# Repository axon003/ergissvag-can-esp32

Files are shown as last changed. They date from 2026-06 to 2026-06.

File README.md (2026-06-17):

# ErgissVAG CAN — ESP32 listen-only CAN tap for VW / Seat / Škoda / Audi

Open-source ESP32 firmware that taps the **CAN-Antrieb / CAN-Komfort** bus of VAG-group
cars (VW, Seat, Škoda, Audi — e.g. Touran, Seat Altea XL) in **listen-only** mode and
streams decoded vehicle data — wheel speeds, yaw rate, steering angle, brake, RPM — as
JSON over WiFi to a companion Android app.

> 📱 **Companion app: [ErgissVAG F16 on Google Play](https://play.google.com/store/apps/details?id=ro.ergiss.vag.f16)**
> — live VAG dashboard, gauges and trip telemetry. This firmware is the optional hardware
> module that feeds it the original CAN data the OBD port doesn't expose.

## Why
The OBD-II port on VAG cars exposes only a limited PID set through the J533 gateway.
Signals like individual **wheel speeds, yaw rate, lateral acceleration, steering angle and
original brake data** live on the internal CAN-Antrieb bus. This module is a **passive,
listen-only tap** — it never writes to the bus (safe, non-intrusive) — that decodes those
frames and serves them to the app over WiFi.

## Features
- ESP32 (native TWAI CAN driver) + SN65HVD230 transceiver — **listen-only, never transmits**
- Decodes CAN-Antrieb (500 kbit) / CAN-Komfort (100 kbit)
- WiFi AP + TCP JSON stream (or STA mode to join your own router)
- Optional GY-85 IMU (accel / gyro / magnetometer) + BMP280 barometer for motion & altitude
- Deep-sleep with wake-on-CAN — sleeps when the car is off
- 3D-printable enclosure (`case.scad` / `case.stl`)
- Two build layouts: Arduino IDE sketch (`ergissvag_can/`) and PlatformIO (`esp32/`)

## Hardware
- ESP32 DevKit v1 + SN65HVD230 CAN transceiver
- (optional) GY-85 IMU + BMP280

⚠️ **Safety:** listen-only tap, inline fuse, never connect TX. You are responsible for any
work on your vehicle's wiring.

## Quick start
1. Flash via PlatformIO (`pio run -t upload`) or Arduino IDE (open `ergissvag_can.ino`).
2. In `config.h` set your own `WIFI_AP_PASS` (STA fields are placeholders by default).
3. Power the module, connect the **ErgissVAG F16** app to the WiFi AP — data flows as JSON.

## License
**PolyForm Noncommercial License 1.0.0** — free for noncommercial use. See [`LICENSE.md`](LICENSE.md).
**Commercial use requires a separate license** — contact **office@ergiss.ro**.

Copyright © Gabriel Diaconu / ERGISS Media.

---
Built by **ERGISS Media** — [ergiss.ro](https://www.ergiss.ro) · [mensoft.ro](https://www.mensoft.ro)
Android: **[ErgissVAG F16 on Google Play](https://play.google.com/store/apps/details?id=ro.ergiss.vag.f16)**

## Support

If this helps you, you can buy me a coffee: **[paypal.me/axon003](https://paypal.me/axon003)**. Thank you!

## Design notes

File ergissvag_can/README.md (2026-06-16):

# ergissvag_can — Arduino IDE sketch

Arduino IDE build (folder name = sketch name). Functionally equivalent to `esp32/` (PlatformIO).

## Arduino IDE setup

### 1. ESP32 board

`File → Preferences → Additional Boards Manager URLs`:
```
https://raw.githubusercontent.com/espressif/arduino-esp32/gh-pages/package_esp32_index.json
```
Then `Tools → Board → Boards Manager` → search **"esp32"** by Espressif → install the latest (3.x+).

Select board: **Tools → Board → ESP32 Arduino → ESP32 Dev Module**
Upload speed: 921600
Flash size: 4MB
Partition scheme: Default 4MB with spiffs

### 2. Libraries (Sketch → Include Library → Manage Libraries)

| Library | Author | Note |
|---|---|---|
| **Adafruit BMP280 Library** | Adafruit | pressure/temperature sensor |
| **Adafruit ADXL345** | Adafruit | GY-85 accelerometer |
| **Adafruit HMC5883 Unified** | Adafruit | GY-85 magnetometer |
| **Adafruit Unified Sensor** | Adafruit | common dependency (BusIO + Sensor base) |

> ITG3200 (gyroscope) is read raw over I2C in `sensors.cpp` — no library needed.

> `ESPmDNS`, `WiFi`, `driver/twai.h` ship with the ESP32 core — no separate install.

### 3. Open + Upload

`File → Open` → select `ergissvag_can.ino`. The Arduino IDE automatically includes
`config.h`, `sensors.h`, `sensors.cpp` (same folder).

Upload (Ctrl+U) with the ESP32 on USB. On the DevKit V1 you don't need to hold anything —
auto-reset works through the USB-Serial chip.

## Hardware

| Connection | ESP32 pin |
|---|---|
| BMP280 + GY-85 (I2C SDA) | **GPIO 21** |
| BMP280 + GY-85 (I2C SCL) | **GPIO 22** |
| SN65HVD230 CTX (CAN TX) | **GPIO 17** (TX2) |
| SN65HVD230 CRX (CAN RX) | **GPIO 16** (RX2) |
| Module power | **3V3** + **GND** |

## Network access

- mDNS hostname: **`ergisscan.local`**
- TCP JSON server: port **31416**
- WiFi STA: `YOUR_WIFI_SSID` / `YOUR_WIFI_PASSWORD` (set in `config.h`)
- Fallback AP if STA fails: `ergCAN_ESP32` / `ergcan2026`

Test: `nc ergisscan.local 31416` (or `ncat`, `telnet`, `socat`)

## Quick config changes

Edit **`config.h`**:
- `CAN_BITRATE` — 500000 (Antrieb) / 100000 (Komfort)
- `WIFI_STA_SSID` / `WIFI_STA_PASS` — set to your own router
- `SENSOR_SAMPLE_MS` — 100 ms default (10 Hz); 50 ms = 20 Hz; 200 ms = 5 Hz
- `MDNS_HOSTNAME` — change the `.local` name

## See also

- `esp32/` — PlatformIO version (CLI build)
- [ErgissVAG F16 on Google Play](https://play.google.com/store/apps/details?id=ro.ergiss.vag.f16) — companion app

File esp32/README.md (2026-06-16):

# ergissvag_can — ESP32 J533 CAN tap (listen-only)

ESP32 DevKit v1 + SN65HVD230 firmware that sniffs the **CAN-Antrieb** or **CAN-Komfort**
bus (VW PQ35 — Seat Altea XL 2011 / Touran CBZB, J533 gateway) and streams decoded frames
as JSON over TCP to a companion Android app
([**ErgissVAG F16**](https://play.google.com/store/apps/details?id=ro.ergiss.vag.f16)).

- Author: Gabriel Diaconu (ERGISS Media)
- Version: 1.0 (2026-04-22)
- Framework: PlatformIO + Arduino-ESP32
- CAN driver: native ESP32 TWAI (`driver/twai.h`)

## Layout

```
esp32/
  platformio.ini      # board esp32dev + arduino framework
  src/
    main.cpp          # firmware (TWAI + WiFi AP + TCP server + deep sleep)
    config.h          # constants (bitrate, SSID, TCP port, pins, timing)
  README.md
```

## Flash

### PlatformIO (recommended)

```bash
cd esp32
pio run                              # compile
pio run -t upload                    # flash via USB (auto-detect port)
pio device monitor -b 115200         # serial log
```

### Arduino IDE

1. Board Manager -> install `esp32` by Espressif Systems
2. Board: `ESP32 Dev Module`, Upload speed 921600, Flash 4MB, Partition `Default`
3. Copy `src/main.cpp` as `main.ino` into a `main/` folder, put `config.h` next to it
4. Tools -> Port, Upload, then Serial Monitor 115200

## Config

Edit `src/config.h`:

| Define | Default | Note |
|---|---|---|
| `CAN_BITRATE` | 500000 | 500k = Antrieb, 100k = Komfort |
| `WIFI_AP_SSID` | `ergCAN_ESP32` | |
| `WIFI_AP_PASS` | `ergcan2026` | WPA2, min 8 chars — **change this** |
| `TCP_PORT` | 31416 | |
| `DEEP_SLEEP_IDLE_S`  | 30 | seconds with no client -> sleep |
| `HB_INTERVAL_MS` | 5000 | heartbeat JSON when no frames |

After editing: `pio run -t upload`.

## Wiring

### ESP32 DevKit v1 <-> SN65HVD230

```
   ESP32 DevKit v1                 SN65HVD230 (listen-only)
   +---------------+                +------------------+
   | GPIO21 (CTX)  |--------------->| D  (TXD)         |   not electrically driving the bus
   |               |                |                  |   (listen-only), but required to init TWAI
   | GPIO22 (CRX)  |<---------------| R  (RXD)         |
   | 3V3           |--------------->| VCC (3V3)        |
   | GND           |--------------->| GND              |
   |               |                | RS   ----- GND   |   <-- REQUIRED: high-speed mode
   |               |                | CANH ----------- | ---> J533 pin 6 (CAN-Antrieb HIGH)
   |               |                | CANL ----------- | ---> J533 pin 16 (CAN-Antrieb LOW)
   +---------------+                +------------------+
```

Notes:
- **RS to GND**: forces the SN65HVD230 into high-speed mode. For passive listen-only the
  driver simply never transmits (`TWAI_MODE_LISTEN_ONLY`). RS to 3V3 would enable
  slope-control (not wanted here).
- **Do NOT** add a 120R termination resistor — the bus is already terminated in the car.
- Keep CAN-H/L a **twisted pair**, 10-30 cm, not run parallel to the 12V supply.
- Power: the ESP32 on-board 3V3 regulator from 5V USB, or a 5V buck from OBD. For a
  permanent install use a 12V->5V step-down with quiescent current <1 mA.

### J533 gateway pinout — PQ35 (Altea XL / Touran / Leon 1P)

Connector T20a (green, 20-pin):

| Pin | Signal | Rate |
|-----|---|---|
| 6 | CAN-Antrieb HIGH | 500 kbps |
| 16  | CAN-Antrieb LOW | 500 kbps |

Connector T20b carries CAN-Komfort HIGH/LOW (100 kbps) and CAN-Infotainment (100 kbps).
J533 pinouts for the PQ35 platform are widely documented (see VW SSP 269).

## TCP protocol

- Port **31416**, WPA2 SSID **ergCAN_ESP32**, ESP32 IP = **192.168.4.1**
- One client at a time (a second connection is rejected)
- Banner on connect:
  ```json
  {"hello":"ergCAN","bitrate":500000,"port":31416}
  ```
- CAN frame (one line, `\n`-delimited):
  ```json
  {"ts":1234,"id":"0x470","ext":0,"rtr":0,"len":8,"data":"01 00 00 00 00 00 00 00"}
  ```
  - `ts`   = millis() since ESP32 boot
  - `id`   = hex CAN ID (11-bit or 29-bit depending on `ext`)
  - `ext`  = 0 standard, 1 extended
  - `rtr`  = 0 data, 1 remote transmission request
  - `len`  = DLC (0..8)
  - `data` = hex bytes, space-separated
- Heartbeat every 5 s when no frames arrive:
  ```json
  {"hb":1,"uptime":42,"rx_total":0,"rx_err":0}
  ```

## Android client pattern

```kotlin
// 1. Phone joins SSID "ergCAN_ESP32" (WPA2 "ergcan2026")
// 2. Socket to 192.168.4.1:31416
val sock = Socket()
sock.connect(InetSocketAddress("192.168.4.1", 31416), 3000)
val br = BufferedReader(InputStreamReader(sock.getInputStream()))
while (isActive) {
    val line = br.readLine() ?: break
    val obj = JSONObject(line)
    if (obj.optInt("hb") == 1) continue          // heartbeat
    val id   = obj.getString("id")               // "0x470"
    val len  = obj.getInt("len")
    val data = obj.getString("data")             // "01 00 ..."
    // decode...
}
```

The [ErgissVAG F16](https://play.google.com/store/apps/details?id=ro.ergiss.vag.f16) app
consumes this stream as one of its vehicle-data sources.

## Troubleshooting

| Symptom | Likely cause / fix |
|---|---|
| `rx=0` on Serial, no frames | Check RS=GND (not VCC!), check bitrate (500k/100k) |
| `state=BUS_OFF` in log | Wrong bitrate or CAN_H/L swapped |
| Continuous reboot | TWAI driver crash — check GPIO21/22 are connected |
| Android can't see the SSID | ESP32 in deep sleep — turn ignition on for wake-on-CAN |
| Connect accepted then dropped | Another client already connected (1-client limit) |
| `rx_err` rising fast | Bad termination — do **NOT** add 120R, the car has it |
| AP shows but won't connect | Password min 8 chars; reset ESP32 after changing config |

## Deep sleep & wake-on-CAN

After 30 s with no TCP client, the ESP32 enters deep sleep (~10 uA).
Wake source: GPIO22 (CAN RX) going HIGH — i.e. any bus activity after idle.

On PQ35:
- Ignition OFF, all buses asleep -> ESP32 sleeps
- Ignition ON or remote unlock -> CAN-Komfort/Antrieb wakes -> ESP32 wakes (a few ms)
- After wake the ESP32 restarts the AP + TCP server + TWAI

Average draw: ~80 mA @ 3V3 when active (WiFi AP), ~10 uA in deep sleep.

## References

- VW Self-Study Programme SSP 269 — CAN Data Bus (Antrieb + Komfort, PQ35)
- [ErgissVAG F16 on Google Play](https://play.google.com/store/apps/details?id=ro.ergiss.vag.f16)

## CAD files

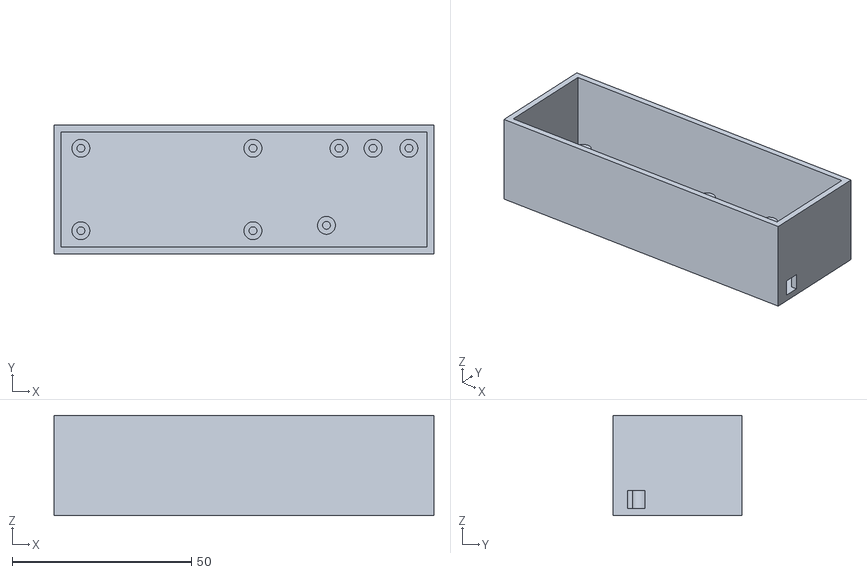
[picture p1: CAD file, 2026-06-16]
case.stl
106.0 x 36.0 x 28.0

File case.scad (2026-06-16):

// case.scad - cutie ESP32 DevKit V1 + 2 module aux (fara capac)
// @author Gabriel Diaconu (ERGISS Media)
// @version 1.2
// @changes
//   v1.0 2026-05-23 - creat initial
//   v1.1 2026-05-23 - adaugat modul 2 (16mm) cu 2 standoff
//   v1.2 2026-05-23 - module dispuse pe lungime (X), nu stivuite pe Y; standoff pe Y ambele

// --- parametri ESP32 DevKit V1 (DOIT 38-pin) ---
esp_pcb_l   = 55;     // lungime PCB (axa X)
esp_pcb_w   = 28;     // latime PCB (axa Y)
esp_hole_dx = 48;     // distanta intre gauri pe X
esp_hole_dy = 23;     // distanta intre gauri pe Y
esp_usb_w   = 10;     // latime cutout microUSB
esp_usb_h   = 6;      // inaltime cutout microUSB

// --- modul 1 (27 x 21.5 mm) ---
mod_l       = 27;     // lungime modul 1 (axa X)
mod_w       = 21.5;   // latime modul 1 (axa Y)
mod_gap     = 10;     // distanta intre ESP si modul 1 (axa X)

// --- modul 2 (16 x 16 mm) ---
mod2_l      = 16;     // lungime modul 2 (axa X)
mod2_w      = 16;     // latime modul 2 (axa Y)
mod2_gap    = 10;     // distanta intre modul 1 si modul 2 (axa X)
mod2_standoff_dx = 10; // separare intre cele 2 standoff modul 2 (axa X)

// --- standoffs ---
standoff_h  = 5;      // inaltime PCB peste podea
standoff_od = 5;      // diametru exterior
standoff_id = 2.2;    // diametru interior (M2.5 self-tap)

// --- cutie ---
wall        = 2;      // grosime perete
floor_h     = 2;      // grosime podea
margin      = 2;      // spatiu liber intre PCB si perete
box_h       = 28;     // inaltime totala perete

// --- derivate ---
inner_l = esp_pcb_l + mod_gap + mod_l + mod2_gap + mod2_l + 2*margin - 20;  // -20: standoff modul 2 mutate la stanga
inner_w = max(esp_pcb_w, mod_w, mod2_w) + 2*margin;
outer_l = inner_l + 2*wall;
outer_w = inner_w + 2*wall;

// pozitii (origine = coltul interior stanga-jos, peste podea)
esp_x0   = margin;
esp_y0   = (inner_w - esp_pcb_w) / 2;
mod_x0   = esp_x0 + esp_pcb_l + mod_gap;
mod_y0   = (inner_w - mod_w) / 2;
mod2_x0  = mod_x0 + mod_l + mod2_gap;
mod2_y0  = (inner_w - mod2_w) / 2;

$fn = 48;

// ===== CUTIE =====
difference() {
    translate([-wall, -wall, 0])
        cube([outer_l, outer_w, box_h]);

    translate([0, 0, floor_h])
        cube([inner_l, inner_w, box_h]);

    // cutout microUSB pe peretele stang
    usb_z_center = floor_h + standoff_h + 1.5;
    translate([-wall - 1, esp_y0 + esp_pcb_w/2 - esp_usb_w/2, usb_z_center - esp_usb_h/2])
        cube([wall + 2, esp_usb_w, esp_usb_h]);

    // cutout 5x5mm pentru fire pe peretele drept (latura scurta), in dreapta jos
    translate([inner_l - 1, margin, floor_h])
        cube([wall + 2, 5, 5]);
}

// ===== STANDOFFS ESP32 (4 colturi) =====
esp_cx = esp_x0 + esp_pcb_l/2;
esp_cy = esp_y0 + esp_pcb_w/2;
for (sx = [-1, 1], sy = [-1, 1])
    translate([esp_cx + sx*esp_hole_dx/2, esp_cy + sy*esp_hole_dy/2, floor_h])
        standoff();

// ===== STANDOFFS MODUL 1 (2 buc: sus la Y-ul ESP, jos cu dify=21.5 difx=-3.5) =====
mod_cx = mod_x0 + mod_l/2;
mod_cy = mod_y0 + mod_w/2;
mod1_top_x = mod_cx - 3;
mod1_top_y = esp_cy + esp_hole_dy/2;     // acelasi Y cu standoff-urile sus ale ESP
mod1_bot_x = mod1_top_x - 3.5;
mod1_bot_y = mod1_top_y - 21.5;
translate([mod1_top_x, mod1_top_y, floor_h]) standoff();
translate([mod1_bot_x, mod1_bot_y, floor_h]) standoff();

// ===== STANDOFFS MODUL 2 (2 buc, ambele sus aliniate la Y-ul ESP, separare pe X) =====
mod2_cx = mod2_x0 + mod2_l/2;
mod2_cy = mod2_y0 + mod2_w/2;
mod2_top_y = esp_cy + esp_hole_dy/2;
for (sx = [-1, 1])
    translate([mod2_cx + sx*mod2_standoff_dx/2 - 20, mod2_top_y, floor_h])
        standoff();

module standoff() {
    difference() {
        cylinder(h = standoff_h, d = standoff_od);
        translate([0, 0, 1])
            cylinder(h = standoff_h, d = standoff_id);
    }
}

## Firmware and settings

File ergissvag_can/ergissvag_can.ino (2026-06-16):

/**
 * main.cpp — ergissvag_can ESP32 J533 CAN tap + sensors + OBD master firmware
 * @author Gabriel Diaconu (ERGISS Media)
 * @version 1.24
 * @changes
 *   v1.24 2026-05-24
 *     - Fix `can` flag fals positive in discovery JSON: era doar `g_can_ok && g_can_bus_ok`,
 *       dar in listen-only fara TX, BUS_OFF nu se declanseaza chiar fara bus efectiv →
 *       flag ramanea true ne-corect. Adaugat verificare `lastFrameMs` (frame primit in <10s).
 *       APK corect trece pe ELM ca sursa OBD cand ergCAN nu primeste frame-uri.
 *   v1.23 2026-05-23
 *     - print_sensor_status() — sumar BMP/ADXL/ITG/MAG, apelat in init si la fiecare STAT (10s).
 *       Asa user vede status init si daca Serial Monitor s-a deschis dupa boot.
 *   v1.22 2026-05-23
 *     - Flag nou DEBUG_SERIAL_QUIET in config.h: cand 1 → emitJson() omitem Serial
 *       (Serial Monitor curat pt diagnoza init/scan/STAT). TCP continua sa trimita
 *       JSON normal pt APK. Default 0 = JSON pe ambele (Serial + TCP).
 *     - I2C revert 50kHz → 400kHz (cleanup test). Tot magnetometru absent — confirmat
 *       chip lipsa fizica; alimentare 5V pe pinul "3.3V" GY-85 (LDO intern) e singurul
 *       test ramas conform tutorial Instructables.
 *   v1.21 2026-05-23
 *     - I2C frecventa 400kHz → 50kHz (test detectie magnetometru cu timing extra tolerant).
 *   v1.20 2026-05-23
 *     - emitJson() reactivat pe Serial — JSON sensors stream apare din nou pe USB-Serial,
 *       pt conectare APK via USB CDC ACM ca alternativa la TCP/WiFi (port 31416).
 *       Serial Monitor in Arduino IDE va arata spam JSON la 10Hz — pt diagnoza pura,
 *       comentat Serial.write linia 230.
 *   v1.19 2026-05-23
 *     - Cleanup debug: I2C 100k → 400k, DISABLE_BMP280 → 0, dump 0x2C scos din STAT
 *       (chip identificat ca EEPROM pasiv board, ignorat). Scan I2C ramane in STAT 10s
 *       pt monitoring. Concluzie: HMC5883L lipseste fizic — cumpara GY-271 pt compass.
 *   v1.18 2026-05-23
 *     - DISABLE_BMP280=1 in config.h → test daca BMP280 init blocheaza HMC5883L pe bus.
 *       Daca dupa flash scan-ul arata 0x1E sau 0x0D → BMP cauzeaza conflict.
 *   v1.17 2026-05-23
 *     - sensors_debug_print() dump extins 0x2C reg 0x00..0x3F + activity test (2 citiri
 *       la 500ms distanta) — vad daca chip pasiv (EEPROM/OTP/ID) sau activ (sensor).
 *   v1.16 2026-05-23
 *     - sensors_debug_print() extins: forced-read probe pe 0x0C/0x0D/0x0E/0x1C/0x1D/0x1E/0x1F
 *       (toate adresele magnetometre cunoscute — pt cazul cand chip-ul prezent dar bug-uit
 *       nu raspunde la write-probe scan dar raspunde la read direct). HMC5883L ID check
 *       la 0x1E ('H','4','3' confirm).
 *   v1.15 2026-05-23
 *     - I2C frecventa scazuta 400kHz → 100kHz (standard mode) — tolerant la pull-up
 *       dublu (GY-85 + BMP280 ambele cu onboard pull-up) si cabluri zgomotoase.
 *   v1.14 2026-05-23
 *     - sensors_debug_print() apelat la fiecare ciclu STAT (10s) → scan I2C + dump 0x2C +
 *       write-read test vizibile si daca Serial Monitor a fost deschis dupa boot ESP32.
 *   v1.13 2026-05-23
 *     - Diagnoza adresa I2C 0x2C neasteptata: dump primii 16 regs + write-read test.
 *       Pattern-ul output identifica chip-ul (sau confirma ghost ACK).
 *   v1.12 2026-05-23
 *     - emitJson() NU mai trimite pe Serial (doar TCP). Serial Monitor ramane curat —
 *       vezi clar init logs ([I2C] scan + sensor detect + [WiFi] + [TCP] + [STAT] 10s).
 *       Pt re-activare debug Serial: decomenteaza Serial.write linia in emitJson().
 *   v1.11 2026-05-23
 *     - i2c_scan_print() la boot — printeaza toate adresele I2C detectate (diagnoza
 *       magnetometru). Vezi Serial Monitor: "[I2C] scan: 0x1E 0x53 0x68 0x76 (4 devices)"
 *       sau similar. Daca apare adresa neasteptata pt magnetometru → identificam clona.
 *   v1.10 2026-05-23
 *     - Magnetometru detect auto HMC5883L (Honeywell @0x1E) sau QMC5883L (QST clone @0x0D).
 *       Init manual via I2C (NU Adafruit_HMC5883_U care esueaza tacit pe clone) → date reale.
 *     - JSON "mag":{"chip":"HMC|QMC|none",...} pt diagnoza. APK ignora field-ul (parser flat).
 *     - Verificare ID HMC (regs 0x0A-C='H43') inainte init; QMC SET/RESET 0x01 + control 0x09.
 *     - Conversie LSB→µT corecta per chip (HMC 1.3G=10.9 LSB/µT, QMC 2G=12 LSB/µT).
 *   v1.9 2026-05-23
 *     - Fix bug "STA pierdut definitiv": dupa AP fallback, ESP32 retry STA la fiecare
 *       WIFI_STA_RETRY_S (60s). Cand HU hotspot/router revine dupa cadere, ESP32 se
 *       reconecteaza automat fara reboot. Inainte ramanea in AP `ergCAN_ESP32` la infinit.
 *   v1.8 2026-05-23
 *     - Discovery JSON include "can":<0|1> = stare CAN (g_can_ok && g_can_bus_ok).
 *     - APK F16 decide sursa OBD: can=1 → ergCAN inlocuieste BT ELM; can=0 → ELM ramane
 *       activ pt OBD, dar ergCAN ramane sursa pentru BMP280 + GY-85 (atitudine/BARO/IMU).
 *   v1.7 2026-05-23
 *     - UDP discovery trimite pe TREI destinatii: (1) UNICAST la gateway (WiFi.gatewayIP())
 *       — esential cand HU ruleaza hotspot; Android hotspot izoleaza broadcast intre clienti AP,
 *       dar nu filtreaza unicast catre gateway-ul AP-ului (HU);
 *       (2) Subnet broadcast (WiFi.broadcastIP() = ex 192.168.43.255) — pt alte device-uri din retea;
 *       (3) Limited 255.255.255.255 — fallback (mai mult Android-uri blocheaza, dar nu strica).
 *     - Confirmat functional cu HU + ESP32 client pe hotspot HU (varianta 1 = unicast).
 *   v1.6 2026-05-23
 *     - UDP broadcast discovery la fiecare UDP_BC_INTERVAL_MS (3s) pe 255.255.255.255:31417
 *     - Mesaj JSON {"app":"ergCAN","ip":"<IP>","tcp_port":31416,"ts":..,"fw":"1.7"}
 *     - APK F16 asculta UDP si auto-pornit TCP catre IP-ul descoperit. La 3 lipsuri (9s)
 *       APK marcheaza ergCAN offline si revine la fallback (BT ELM / device sensors).
 *     - Activ dupa WiFi STA up (sau AP fallback) — pornit din netServicesUp(); merge si in AP mode.
 *   v1.0 2026-04-22 — creat initial
 *     - TWAI listen-only (500k Antrieb / 100k Komfort config-selectabil)
 *     - WiFi AP "ergCAN_ESP32" (1 client)
 *     - TCP server port 31416, 1 frame = 1 linie JSON
 *     - Heartbeat 5s cand fara frames
 *     - Deep sleep 30s fara client + wake-on-CAN
 *     - Reboot auto la TWAI bus-off / hw error
 *   v1.1 2026-05-23
 *     - CAN mutat pe RX2/TX2 (GPIO 16/17) — 21/22 ocupati de I2C BMP280+GY-85
 *     - WiFi STA mode catre router "YOUR_WIFI_SSID" (cu fallback AP daca esueaza)
 *     - Senzori BMP280 + GY-85 (ADXL345 + ITG3200 + HMC5883L) pe I2C 21/22 @ 400kHz
 *     - JSON sensors emis pe Serial si TCP la fiecare 100ms (10Hz)
 *     - Scos deep sleep (alimentare din USB HU se taie cu contactul)
 *   v1.2 2026-05-23
 *     - mDNS hostname "ergisscan.local" — accesibil din LAN fara IP (nu are afisaj)
 *     - DHCP hostname set in STA mode (apare in lista router ca "ergisscan")
 *     - Anunt serviciu _ergcan._tcp.31416 pentru auto-discovery
 *   v1.3 2026-05-23
 *     - WiFi connect NON-BLOCKING — sensors+CAN+Serial emit imediat la boot
 *     - State machine in loop: WIFI_STA_TRYING -> WIFI_STA_OK | WIFI_AP_OK
 *     - mDNS + TCP server pornesc DUPA ce WiFi e up (la transition)
 *     - HU boot poate dura zeci de sec, dar Serial USB merge instant
 *   v1.4 2026-05-23
 *     - TWAI mode NORMAL (era LISTEN_ONLY) — pot transmite query OBD2/UDS pe bus
 *     - ISO-TP layer (iso_tp.cpp) — SF + FF/CF/FC, multi-ECU broadcast collection
 *     - OBD/UDS commands (obd_cmd.cpp) — mode 01/03/04/07/09 + UDS 10/19/22
 *     - USB JSON command parser (usb_proto.cpp) — F16 trimite query, ESP32 dispatches
 *     - DTC se citeste in broadcast 0x7DF → toate ECU-urile raspund pe 7E8-7EF
 *   v1.5 2026-05-23
 *     - Auto-recovery la BUS_OFF (fara reboot) — sensors+WiFi continua functional
 *     - Flag global g_can_bus_ok — iso_tp blocheaza TX cand bus absent
 *     - Eveniment JSON "buststate" emit la trans tranzitiile ok/bus_off
 *     - Alerts ALERT_BUS_RECOVERY_IN_PROGRESS / ALERT_BUS_RECOVERY_COMPLETE wired
 *
 * Hardware:
 *   ESP32 DevKit v1
 *     + SN65HVD230 (RS=GND silent listen-only)
 *       GPIO17 (TX2) -> CTX  (neconectat electric la CAN, doar init driver)
 *       GPIO16 (RX2) <- CRX
 *       3V3 + GND
 *       CAN_H/CAN_L la J533 pin 6/16 (CAN-Antrieb PQ35)
 *     + BMP280 (3.3V version) — adresa 0x76
 *     + GY-85 9DOF (ADXL345 0x53 + ITG3200 0x68 + HMC5883L 0x1E)
 *       3V3 + GND + GPIO21 (SDA) + GPIO22 (SCL)
 */

#include <Arduino.h>
#include <WiFi.h>
#include <WiFiServer.h>
#include <WiFiClient.h>
#include <WiFiUdp.h>
#include <ESPmDNS.h>
#include "driver/twai.h"
#include "esp_system.h"
#include "config.h"
#include "sensors.h"
#include "iso_tp.h"
#include "obd_cmd.h"
#include "usb_proto.h"

// ===== State =====
static WiFiServer tcpServer(TCP_PORT);
static WiFiClient tcpClient;
static WiFiUDP    udpDisc;             // UDP broadcast discovery 255.255.255.255:31417
static uint32_t   lastUdpBcMs = 0;

static uint32_t rxTotal      = 0;
static uint32_t rxErr        = 0;
static uint32_t lastFrameMs  = 0;
static uint32_t lastHbMs     = 0;
static uint32_t lastStatsMs  = 0;
static uint32_t lastSensorMs = 0;
static uint32_t ledOffAt     = 0;
static uint32_t bootMs       = 0;
static bool     g_can_ok     = false;

// WiFi state machine (non-blocking connect)
enum WifiState : uint8_t {
    WIFI_STA_TRYING,    // STA.begin() lansat, asteptam status WL_CONNECTED
    WIFI_STA_OK,        // STA conectat, mDNS+TCP up
    WIFI_AP_OK          // fallback AP activ dupa timeout STA
};
static WifiState g_wifi_state    = WIFI_STA_TRYING;
static uint32_t  g_wifi_start_ms = 0;
static bool      g_net_services_up = false;   // mDNS + TCP server pornite

// CAN bus state — blocheaza TX iso_tp cand bus absent (evita BUS_OFF loop)
volatile bool g_can_bus_ok = true;             // extern in iso_tp.cpp

// ===== Helpers =====

static void ledPulse() {
    digitalWrite(LED_PIN, HIGH);
    ledOffAt = millis() + LED_BLINK_MS;
}

static void ledService() {
    if (ledOffAt != 0 && (int32_t)(millis() - ledOffAt) >= 0) {
        digitalWrite(LED_PIN, LOW);
        ledOffAt = 0;
    }
}

static bool twaiTimingFor(uint32_t bps, twai_timing_config_t &out) {
    switch (bps) {
        case 1000000: out = TWAI_TIMING_CONFIG_1MBITS();   return true;
        case 800000:  out = TWAI_TIMING_CONFIG_800KBITS(); return true;
        case 500000:  out = TWAI_TIMING_CONFIG_500KBITS(); return true;
        case 250000:  out = TWAI_TIMING_CONFIG_250KBITS(); return true;
        case 125000:  out = TWAI_TIMING_CONFIG_125KBITS(); return true;
        case 100000:  out = TWAI_TIMING_CONFIG_100KBITS(); return true;
        case 50000:   out = TWAI_TIMING_CONFIG_50KBITS();  return true;
        default:      return false;
    }
}

static bool twaiStart() {
    // Mode NORMAL (era LISTEN_ONLY) — pot transmite OBD/UDS query pe bus
    // Sniffing pasiv RX continua sa functioneze identic
    twai_general_config_t g = TWAI_GENERAL_CONFIG_DEFAULT(
        CAN_TX_PIN, CAN_RX_PIN, TWAI_MODE_NORMAL
    );
    g.rx_queue_len = TWAI_RX_QUEUE_LEN;
    g.tx_queue_len = TWAI_TX_QUEUE_LEN_NORMAL;
    g.alerts_enabled = TWAI_ALERT_BUS_OFF | TWAI_ALERT_BUS_ERROR
                      | TWAI_ALERT_RX_QUEUE_FULL | TWAI_ALERT_ERR_PASS
                      | TWAI_ALERT_TX_FAILED
                      | TWAI_ALERT_BUS_RECOVERED;

    twai_timing_config_t t;
    if (!twaiTimingFor(CAN_BITRATE, t)) {
        Serial.printf("[TWAI] bitrate %u nesuportat\n", CAN_BITRATE);
        return false;
    }
    twai_filter_config_t f = TWAI_FILTER_CONFIG_ACCEPT_ALL();

    esp_err_t e = twai_driver_install(&g, &t, &f);
    if (e != ESP_OK) {
        Serial.printf("[TWAI] driver_install err 0x%x\n", e);
        return false;
    }
    e = twai_start();
    if (e != ESP_OK) {
        Serial.printf("[TWAI] start err 0x%x\n", e);
        twai_driver_uninstall();
        return false;
    }
    Serial.printf("[TWAI] OK NORMAL mode @%u bps  (TX=GPIO%d RX=GPIO%d)\n",
                  CAN_BITRATE, (int)CAN_TX_PIN, (int)CAN_RX_PIN);
    return true;
}

static void twaiStopAndReboot(const char *why) {
    Serial.printf("[TWAI] FATAL %s -> reboot\n", why);
    twai_stop();
    twai_driver_uninstall();
    delay(200);
    esp_restart();
}

// Format 1 TWAI message -> 1 line JSON
static size_t frameToJson(const twai_message_t &m, char *buf, size_t bufSz) {
    char dataHex[3 * 8 + 1];
    dataHex[0] = 0;
    size_t dlc = m.data_length_code;
    if (dlc > 8) dlc = 8;
    size_t p = 0;
    for (size_t i = 0; i < dlc; ++i) {
        if (i) dataHex[p++] = ' ';
        static const char H[] = "0123456789ABCDEF";
        dataHex[p++] = H[(m.data[i] >> 4) & 0xF];
        dataHex[p++] = H[m.data[i] & 0xF];
    }
    dataHex[p] = 0;

    uint32_t canId = m.identifier;
    int ext = (m.flags & TWAI_MSG_FLAG_EXTD) ? 1 : 0;
    int rtr = (m.flags & TWAI_MSG_FLAG_RTR)  ? 1 : 0;

    return snprintf(buf, bufSz,
        "{\"ts\":%lu,\"type\":\"can\",\"id\":\"0x%lX\",\"ext\":%d,\"rtr\":%d,\"len\":%u,\"data\":\"%s\"}\n",
        (unsigned long)millis(),
        (unsigned long)canId,
        ext, rtr,
        (unsigned)m.data_length_code,
        dataHex);
}

// Trimite JSON la Serial (pt USB-Serial APK consume) si TCP (pt WiFi APK).
// Cand DEBUG_SERIAL_QUIET=1 → omitem Serial → Serial Monitor curat pt diagnoza init/scan/STAT.
void emitJson(const char *line, size_t len) {
#if !DEBUG_SERIAL_QUIET
    Serial.write((const uint8_t *)line, len);
#endif
    if (g_net_services_up && tcpClient && tcpClient.connected()) {
        tcpClient.write((const uint8_t *)line, len);
    }
}

static const char *wifiStateName() {
    switch (g_wifi_state) {
        case WIFI_STA_TRYING: return "STA-trying";
        case WIFI_STA_OK:     return "STA";
        case WIFI_AP_OK:      return "AP";
    }
    return "?";
}

static String wifiCurrentIp() {
    if (g_wifi_state == WIFI_STA_OK) return WiFi.localIP().toString();
    if (g_wifi_state == WIFI_AP_OK)  return WiFi.softAPIP().toString();
    return String("0.0.0.0");
}

static void sendHeartbeat() {
    char buf[JSON_BUF_SZ];
    int n = snprintf(buf, sizeof(buf),
        "{\"ts\":%lu,\"type\":\"hb\",\"uptime\":%lu,\"rx_total\":%lu,\"rx_err\":%lu,"
        "\"wifi\":\"%s\",\"ip\":\"%s\",\"rssi\":%d}\n",
        (unsigned long)millis(),
        (unsigned long)((millis() - bootMs) / 1000UL),
        (unsigned long)rxTotal,
        (unsigned long)rxErr,
        wifiStateName(),
        wifiCurrentIp().c_str(),
        g_wifi_state == WIFI_STA_OK ? WiFi.RSSI() : 0);
    if (n > 0) emitJson(buf, (size_t)n);
}

// ===== WiFi non-blocking state machine =====

// Lanseaza tentativa STA (non-blocking — doar setup, nu asteapta connect)
static void wifiStaBeginAsync() {
    Serial.printf("[WiFi] STA begin async to '%s' (timeout %ds)\n",
                  WIFI_STA_SSID, WIFI_STA_TIMEOUT_S);
    WiFi.mode(WIFI_STA);
    WiFi.setSleep(false);
    WiFi.setHostname(MDNS_HOSTNAME);
    WiFi.begin(WIFI_STA_SSID, WIFI_STA_PASS);
    g_wifi_state    = WIFI_STA_TRYING;
    g_wifi_start_ms = millis();
}

static void wifiApFallback() {
    Serial.println("[WiFi] STA timeout -> fallback AP");
    WiFi.disconnect(true);
    WiFi.mode(WIFI_AP);
    WiFi.softAPsetHostname(MDNS_HOSTNAME);
    bool ok = WiFi.softAP(WIFI_AP_SSID, WIFI_AP_PASS,
                          WIFI_AP_CHANNEL, 0, WIFI_AP_MAX_CONN);
    Serial.printf("[WiFi] AP %s ok=%d ip=%s\n",
                  WIFI_AP_SSID, ok ? 1 : 0, WiFi.softAPIP().toString().c_str());
    g_wifi_state = WIFI_AP_OK;
}
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
void loop() {
    ledService();

    // === USB JSON command parser (F16 → ESP32) ===
    usb_proto_service();

    // === ISO-TP timeout cleanup (sesiuni abandonate) ===
    iso_tp_tick(millis());

    // === WiFi state machine (non-blocking) ===
    wifiServiceTick();

    // === UDP discovery broadcast (doar daca services up) ===
    if (g_net_services_up && (millis() - lastUdpBcMs) >= UDP_BC_INTERVAL_MS) {
        lastUdpBcMs = millis();
        sendUdpDiscovery();
    }

    // === TCP accept / drop (doar daca services up) ===
    if (g_net_services_up) {
        if (tcpServer.hasClient()) {
            WiFiClient neu = tcpServer.available();
            if (tcpClient && tcpClient.connected()) {
                neu.stop();   // refuza al doilea
            } else {
                tcpClient = neu;
                tcpClient.setNoDelay(true);
                Serial.printf("[TCP] client connect %s\n",
                              tcpClient.remoteIP().toString().c_str());
                char hello[JSON_BUF_SZ];
                int n = snprintf(hello, sizeof(hello),
                    "{\"ts\":%lu,\"type\":\"hello\",\"app\":\"ergCAN\",\"bitrate\":%u,\"port\":%d,\"can\":%d}\n",
                    (unsigned long)millis(), CAN_BITRATE, TCP_PORT, g_can_ok ? 1 : 0);
                if (n > 0) tcpClient.write((const uint8_t *)hello, n);
            }
        }
        if (tcpClient && !tcpClient.connected()) {
            Serial.println("[TCP] client disconnect");
            tcpClient.stop();
        }
        if (tcpClient && tcpClient.connected()) {
            while (tcpClient.available()) tcpClient.read();   // drain input
        }
    }

    // === TWAI alerts ===
    if (g_can_ok) {
        uint32_t alerts = 0;
        if (twai_read_alerts(&alerts, 0) == ESP_OK && alerts) {
            if (alerts & TWAI_ALERT_BUS_OFF) {
                // Bus absent / nimic conectat → NU reboot. Sensors + WiFi raman live.
                Serial.println("[TWAI] BUS_OFF -> auto-recovery (sensors continua)");
                g_can_bus_ok = false;
                // Flush TX queue (mesaje neacknowledged) si initiere recovery
                twai_clear_transmit_queue();
                twai_initiate_recovery();
                // Notify F16 via JSON event
                char buf[128];
                int n = snprintf(buf, sizeof(buf),
                    "{\"ts\":%lu,\"type\":\"buststate\",\"ok\":0,\"reason\":\"bus_off\"}\n",
                    (unsigned long)millis());
                if (n > 0) emitJson(buf, (size_t)n);
            }
            if (alerts & TWAI_ALERT_BUS_RECOVERED) {
                Serial.println("[TWAI] bus recovered -> restart driver");
                twai_start();
                g_can_bus_ok = true;
                char buf[128];
                int n = snprintf(buf, sizeof(buf),
                    "{\"ts\":%lu,\"type\":\"buststate\",\"ok\":1,\"reason\":\"recovered\"}\n",
                    (unsigned long)millis());
                if (n > 0) emitJson(buf, (size_t)n);
            }
            if (alerts & TWAI_ALERT_BUS_ERROR)     rxErr++;
            if (alerts & TWAI_ALERT_RX_QUEUE_FULL) rxErr++;
            if (alerts & TWAI_ALERT_ERR_PASS) Serial.println("[TWAI] error-passive");
        }

        // === Receive frames (burst <=32 per loop) ===
        int burst = 0;
        while (burst < 32) {
            twai_message_t m;
            esp_err_t r = twai_receive(&m, 0);
            if (r == ESP_ERR_TIMEOUT) break;
            if (r != ESP_OK) { rxErr++; break; }

            rxTotal++;
            lastFrameMs = millis();
            ledPulse();

            char buf[JSON_BUF_SZ];
            size_t n = frameToJson(m, buf, sizeof(buf));
            if (n > 0) emitJson(buf, n);

            // ISO-TP layer: feed every frame to session manager (multi-ECU broadcast collection)
            // Frame-urile in afara range-ului 0x700-0x7FF nu vor crea sesiuni utile, dar
            // codul filtreaza intern prin PCI byte (orice frame care nu e SF/FF/CF e ignorat).
            iso_tp_on_frame(m.identifier, m.data, m.data_length_code);

            burst++;
        }

        // Drain ISO-TP sesiuni complete (OBD responses) → emit JSON per ECU
        iso_tp_drain(obd_process_response);
    }

    uint32_t now = millis();

    // === Sensors @ 10Hz ===
    if ((now - lastSensorMs) >= SENSOR_SAMPLE_MS) {
        lastSensorMs = now;
        SensorData sd;
        sensors_read(sd);
        char buf[JSON_BUF_SZ];
        size_t n = sensors_to_json(sd, buf, sizeof(buf));
        if (n > 0) emitJson(buf, n);
    }

    // === Heartbeat ===
    if ((now - lastHbMs) >= HB_INTERVAL_MS &&
        (now - lastFrameMs) >= HB_INTERVAL_MS) {
        sendHeartbeat();
        lastHbMs = now;
    }

    // === Stats Serial ===
    if ((now - lastStatsMs) >= STATS_INTERVAL_MS) {
        lastStatsMs = now;
        // Diagnoza I2C (scan + dump 0x2C) repetata la fiecare 10s — vizibila si daca Serial
        // Monitor a fost deschis dupa boot ESP32 (cand pierzi mesajele de init).
        sensors_debug_print();
        int rssi = (g_wifi_state == WIFI_STA_OK) ? WiFi.RSSI() : 0;
        int tcpOk = (tcpClient && tcpClient.connected()) ? 1 : 0;
        if (g_can_ok) {
            twai_status_info_t st;
            if (twai_get_status_info(&st) == ESP_OK) {
                Serial.printf("[STAT] rx=%lu err=%lu wifi=%s tcp=%d state=%d tec=%u rec=%u rxQ=%u rssi=%d\n",
                    (unsigned long)rxTotal, (unsigned long)rxErr,
                    wifiStateName(), tcpOk,
                    (int)st.state, (unsigned)st.tx_error_counter,
                    (unsigned)st.rx_error_counter, (unsigned)st.msgs_to_rx, rssi);
            }
        } else {
            Serial.printf("[STAT] CAN=off wifi=%s tcp=%d rssi=%d\n",
                wifiStateName(), tcpOk, rssi);
        }
    }

    delay(1);   // yield
}

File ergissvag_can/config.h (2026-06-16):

/**
 * config.h — ergissvag_can ESP32 firmware configuration
 * @author Gabriel Diaconu (ERGISS Media)
 * @version 1.2
 * @changes
 *   v1.0 2026-04-22 — creat initial; constants firmware (bitrate, WiFi AP, TCP port, deep sleep)
 *   v1.1 2026-05-23 — mutat CAN de pe 21/22 pe 5/4 (I2C ocupa 21/22 acum pt BMP280+GY-85);
 *                     adaugat WiFi STA mode (YOUR_WIFI_SSID), I2C pini, sensor sample rate
 *   v1.2 2026-05-23 — UDP_DISC_PORT 31417 + UDP_BC_INTERVAL_MS 3000 pt auto-discovery LAN.
 */
#ifndef ERGCAN_CONFIG_H
#define ERGCAN_CONFIG_H

// ===== CAN bitrate =====
// 500000 = CAN-Antrieb (powertrain, J533 pin 6+16 PQ35)
// 100000 = CAN-Komfort (comfort bus, J533 pins comfort CAN-L/H)
#define CAN_BITRATE        500000

// ===== Pin map ESP32 DevKit v1 <-> SN65HVD230 =====
// MUTAT 2026-05-23: era 21/22, dar acum I2C ocupa 21/22 (BMP280 + GY-85).
// Folosim RX2/TX2 marcati pe DevKit v1 — pini liberi (UART2 nu e folosit), label clar pe placa.
#define CAN_TX_PIN         GPIO_NUM_17   // TX2 marcat pe placa -> SN65HVD230 CTX (D/TXD)
#define CAN_RX_PIN         GPIO_NUM_16   // RX2 marcat pe placa <- SN65HVD230 CRX (R/RXD)
#define LED_PIN            2             // LED builtin ESP32 DevKit v1

// ===== I2C senzori (BMP280 + GY-85: ADXL345 + ITG3200 + HMC5883L) =====
#define I2C_SDA_PIN        21
#define I2C_SCL_PIN        22
#define I2C_FREQ_HZ        50000        // 400kHz safe pt fire scurte <20cm

// I2C adrese
#define BMP280_I2C_ADDR    0x76          // 0x77 daca SDO=VCC

// Debug: dezactiveaza init BMP280 temporar — pune 1 cand vrei sa testezi daca BMP-ul
// blocheaza magnetometrul (pull-up dublu / interferenta init). Default 0 = BMP normal.
#define DISABLE_BMP280     0

// Debug: cand 1 → Serial Monitor curat (doar init + scan + STAT, FARA stream JSON sensors).
// TCP continua sa trimita JSON normal pt APK. Default 0 = JSON pe ambele (Serial + TCP).
#define DEBUG_SERIAL_QUIET 0
#define ADXL345_I2C_ADDR   0x53          // GY-85 accelerometer
#define ITG3200_I2C_ADDR   0x68          // GY-85 gyroscope
#define HMC5883L_I2C_ADDR  0x1E          // GY-85 magnetometer

// Sample rate senzori
#define SENSOR_SAMPLE_MS   100           // citire la fiecare 100ms (10Hz)

// ===== WiFi STA (conectare la router) — preferinta principala =====
#define WIFI_STA_SSID      "YOUR_WIFI_SSID"
#define WIFI_STA_PASS      "YOUR_WIFI_PASSWORD"
#define WIFI_STA_TIMEOUT_S 20            // dupa atatea sec de tentativa esuata -> fallback AP
#define WIFI_STA_RETRY_S   30            // din AP fallback, reincearca STA la fiecare X sec (revine la HU/router cand redevine accesibil)

// ===== mDNS hostname (.local) — accesibil ca "ergisscan.local" in LAN =====
#define MDNS_HOSTNAME      "ergisscan"

// ===== WiFi AP fallback (daca STA esueaza) =====
#define WIFI_AP_SSID       "ergCAN_ESP32"
#define WIFI_AP_PASS       "ergcan2026"
#define WIFI_AP_CHANNEL    6
#define WIFI_AP_MAX_CONN   1

// ===== TCP server =====
#define TCP_PORT           31416          // 31415 e rezervat ErgissVAG BCAST; 31416 = ergCAN

// ===== UDP discovery broadcast =====
// ESP32 anunta presenta in LAN dupa WiFi STA up. APK F16 asculta UDP pe 31417 →
// la receptie auto-pornit TCP client catre TCP_PORT 31416. Daca lipsesc 3 broadcast-uri
// la rand (=> 9s), APK marcheaza ergCAN offline si revine la fallback (BT ELM / device).
#define UDP_DISC_PORT          31417
#define UDP_BC_INTERVAL_MS     3000

// ===== Timing =====
#define DEEP_SLEEP_IDLE_S  300            // 5 min fara client -> deep sleep (era 30s; marit pt debug/test)
#define HB_INTERVAL_MS     5000           // heartbeat JSON daca fara frames
#define STATS_INTERVAL_MS  10000          // log statistici Serial
#define LED_BLINK_MS       20             // durata puls LED la RX frame

// ===== Buffers =====
#define TWAI_RX_QUEUE_LEN  64
#define TWAI_TX_QUEUE_LEN         0       // legacy (listen-only) — pastrat pt compat referinte
#define TWAI_TX_QUEUE_LEN_NORMAL  8       // pentru OBD/UDS query active in mode NORMAL
#define JSON_BUF_SZ        320            // marit pt sensor frame (mai multe fields)

#endif // ERGCAN_CONFIG_H

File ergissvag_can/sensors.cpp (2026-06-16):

/**
 * sensors.cpp — BMP280 + GY-85 reader implementation
 * @author Gabriel Diaconu (ERGISS Media)
 * @version 1.2
 * @changes
 *   v1.0 2026-05-23 — creat initial
 *   v1.2 2026-05-23 — i2c_scan_print() printeaza la boot toate adresele I2C prezente
 *                     (diagnoza pt magnetometru "none" — daca apar adrese neasteptate,
 *                     senzorul poate fi clona cu adresa diferita ex AK8963=0x0C / IST8310=0x0E).
 *   v1.1 2026-05-23 — magnetometru detect HMC5883L (0x1E) + QMC5883L (0x0D) cu init manual I2C
 *                     (nu Adafruit_HMC5883 — esueaza tacit pe clone returnand 0). Tip chip
 *                     raportat in JSON ca "chip":"HMC|QMC|none". Conversie LSB→µT corecta
 *                     per chip (HMC 1.3G=10.9 LSB/µT, QMC 2G=12 LSB/µT).
 */
#include "sensors.h"
#include "config.h"
#include <Wire.h>
#include <Adafruit_BMP280.h>
#include <Adafruit_ADXL345_U.h>
#include <math.h>

static Adafruit_BMP280            bmp;
static Adafruit_ADXL345_Unified   accel(12345);

static bool g_bmp_present   = false;
static bool g_accel_present = false;
static bool g_gyro_present  = false;
static bool g_mag_present   = false;

// Magnetometru — tip chip detectat
enum MagChip : uint8_t { MAG_NONE = 0, MAG_HMC = 1, MAG_QMC = 2 };
static MagChip g_mag_chip = MAG_NONE;
#define HMC5883L_ADDR  0x1E
#define QMC5883L_ADDR  0x0D

// ----- I2C helpers generice -----

static bool i2c_write_reg(uint8_t addr, uint8_t reg, uint8_t val) {
    Wire.beginTransmission(addr);
    Wire.write(reg);
    Wire.write(val);
    return Wire.endTransmission() == 0;
}

static bool i2c_read_regs(uint8_t addr, uint8_t reg, uint8_t *buf, size_t len) {
    Wire.beginTransmission(addr);
    Wire.write(reg);
    if (Wire.endTransmission(false) != 0) return false;
    size_t got = Wire.requestFrom((int)addr, (int)len, (int)true);
    if (got != len) return false;
    for (size_t i = 0; i < len; ++i) buf[i] = Wire.read();
    return true;
}

static bool i2c_probe(uint8_t addr) {
    Wire.beginTransmission(addr);
    return Wire.endTransmission() == 0;
}

// ----- HMC5883L (Honeywell original) — init manual -----

static bool hmc_init() {
    if (!i2c_probe(HMC5883L_ADDR)) return false;
    // Verifica ID: reg 0x0A,0x0B,0x0C = 'H','4','3' = 0x48,0x34,0x33
    uint8_t id[3];
    if (!i2c_read_regs(HMC5883L_ADDR, 0x0A, id, 3)) return false;
    if (id[0] != 'H' || id[1] != '4' || id[2] != '3') {
        Serial.printf("[I2C] 0x1E raspunde dar ID = %02X %02X %02X (NU HMC5883L)\n", id[0], id[1], id[2]);
        return false;
    }
    // ConfigA (0x00): 8 samples avg, 15 Hz, normal
    if (!i2c_write_reg(HMC5883L_ADDR, 0x00, 0x70)) return false;
    // ConfigB (0x01): gain 1.3 Ga (default; 1090 LSB/Gauss = 10.9 LSB/µT)
    if (!i2c_write_reg(HMC5883L_ADDR, 0x01, 0x20)) return false;
    // Mode (0x02): continuous measurement
    if (!i2c_write_reg(HMC5883L_ADDR, 0x02, 0x00)) return false;
    return true;
}

// HMC data: 0x03..0x08 = X H, X L, Z H, Z L, Y H, Y L (X-Z-Y order!)
static bool hmc_read(float &mx, float &my, float &mz) {
    uint8_t b[6];
    if (!i2c_read_regs(HMC5883L_ADDR, 0x03, b, 6)) return false;
    int16_t rx = (int16_t)((b[0] << 8) | b[1]);
    int16_t rz = (int16_t)((b[2] << 8) | b[3]);
    int16_t ry = (int16_t)((b[4] << 8) | b[5]);
    // Saturated reading sentinel = -4096
    if (rx == -4096 || ry == -4096 || rz == -4096) return false;
    const float LSB_PER_UT = 10.9f;  // 1.3 Ga range
    mx = (float)rx / LSB_PER_UT;
    my = (float)ry / LSB_PER_UT;
    mz = (float)rz / LSB_PER_UT;
    return true;
}

// ----- QMC5883L (QST clone — frecvent in GY-85/GY-271 noi) — init manual -----

static bool qmc_init() {
    if (!i2c_probe(QMC5883L_ADDR)) return false;
    // Soft reset (control 2 reg 0x0A bit 7)
    i2c_write_reg(QMC5883L_ADDR, 0x0A, 0x80);
    delay(10);
    // SET/RESET period (recomandat 0x01)
    if (!i2c_write_reg(QMC5883L_ADDR, 0x0B, 0x01)) return false;
    // Control 1 (0x09): OSR=512 (00), RNG=2G (00), ODR=50Hz (10), MODE=continuous (01) → 0b00001001 = 0x09
    if (!i2c_write_reg(QMC5883L_ADDR, 0x09, 0x09)) return false;
    return true;
}

// QMC data: 0x00..0x05 = X L, X H, Y L, Y H, Z L, Z H (LSB first!)
static bool qmc_read(float &mx, float &my, float &mz) {
    uint8_t b[6];
    if (!i2c_read_regs(QMC5883L_ADDR, 0x00, b, 6)) return false;
    int16_t rx = (int16_t)((b[1] << 8) | b[0]);
    int16_t ry = (int16_t)((b[3] << 8) | b[2]);
    int16_t rz = (int16_t)((b[5] << 8) | b[4]);
    const float LSB_PER_UT = 12.0f;  // 2 Ga range: 12000 LSB/Gauss
    mx = (float)rx / LSB_PER_UT;
    my = (float)ry / LSB_PER_UT;
    mz = (float)rz / LSB_PER_UT;
    return true;
}

// ----- ITG3200 raw I2C helpers -----

static bool itg_write_reg(uint8_t reg, uint8_t val) {
    Wire.beginTransmission(ITG3200_I2C_ADDR);
    Wire.write(reg);
    Wire.write(val);
    return Wire.endTransmission() == 0;
}

static bool itg_read_regs(uint8_t reg, uint8_t *buf, size_t len) {
    Wire.beginTransmission(ITG3200_I2C_ADDR);
    Wire.write(reg);
    if (Wire.endTransmission(false) != 0) return false;
    size_t got = Wire.requestFrom((int)ITG3200_I2C_ADDR, (int)len, (int)true);
    if (got != len) return false;
    for (size_t i = 0; i < len; ++i) buf[i] = Wire.read();
    return true;
}

static bool itg_init() {
    // WHO_AM_I (0x00) trebuie sa fie 0x68 (sau adresa I2C - bit 0)
    uint8_t who;
    if (!itg_read_regs(0x00, &who, 1)) return false;
    if ((who & 0x7E) != 0x68) return false;

    // Sample Rate Divider (0x15) = 7 -> 1kHz / 8 = 125Hz
    if (!itg_write_reg(0x15, 0x07)) return false;
    // DLPF (0x16): FS_SEL=3 (±2000°/s full scale), DLPF_CFG=3 (BW 42Hz, internal 1kHz)
    if (!itg_write_reg(0x16, 0x1B)) return false;
    // Power: clock source = X-gyro reference
    if (!itg_write_reg(0x3E, 0x01)) return false;
    return true;
}
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

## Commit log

2026-06-16 ErgissVAG CAN — ESP32 listen-only J533 tap (companion firmware for ErgissVAG F16)
    [case.scad, case.stl]
2026-06-16 Remove RO wiring guide (J533 pinout is widely documented)
2026-06-17 Add donate link (PayPal) + Sponsor button
2026-09-29 Update firmware to 2.6.0: named parameters, generic profile autodetect, UDS diagnostics
    The Arduino sketch (ergissvag_can/) was stuck at the initial 2026-05-23 snapshot; bring it
    up to date with the current private development (fw 2.6.0):
    - Named-parameter subscriptions (sub {"n":"rpm"}): the board resolves a name via vehicle
    profile -> vehicle-specific values (odometer/fuel/generator/oil) -> standard OBD-II
    catalog (45 parameters, params.cpp/params.h), reporting the source. Old PID-based
    subscriptions still work.
    - Generic vehicle profile with bitrate/addressing autodetection (500k/250k x 11/29-bit),
    listen-first before any transmit; PARAMS and AUTODET console commands.
    - Bitmap of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
